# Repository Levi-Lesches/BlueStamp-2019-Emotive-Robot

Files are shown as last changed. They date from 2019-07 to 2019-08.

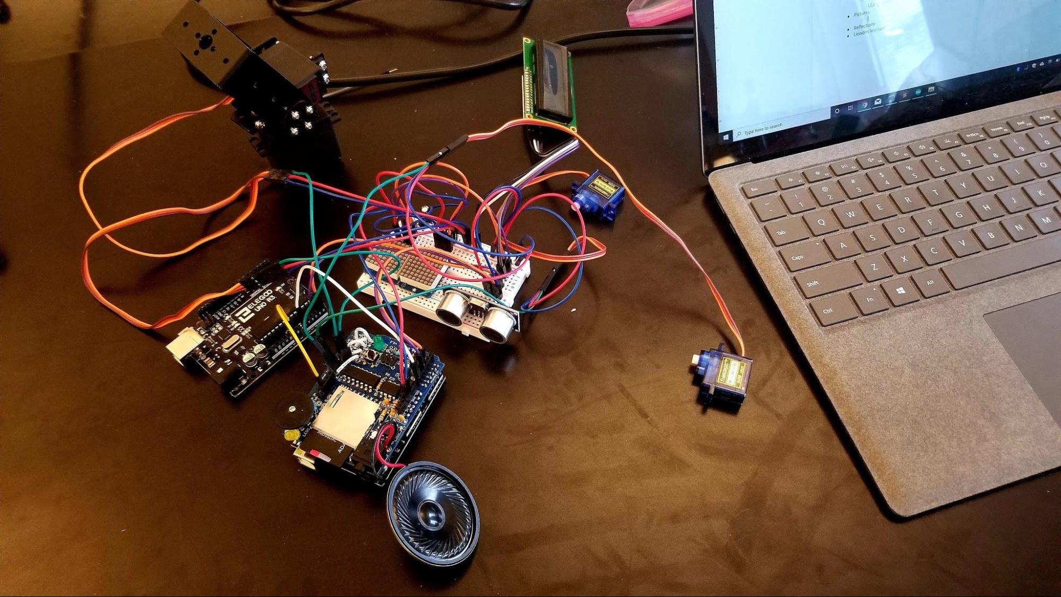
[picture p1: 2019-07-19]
documentation/Second Milestone/images/image2.jpg

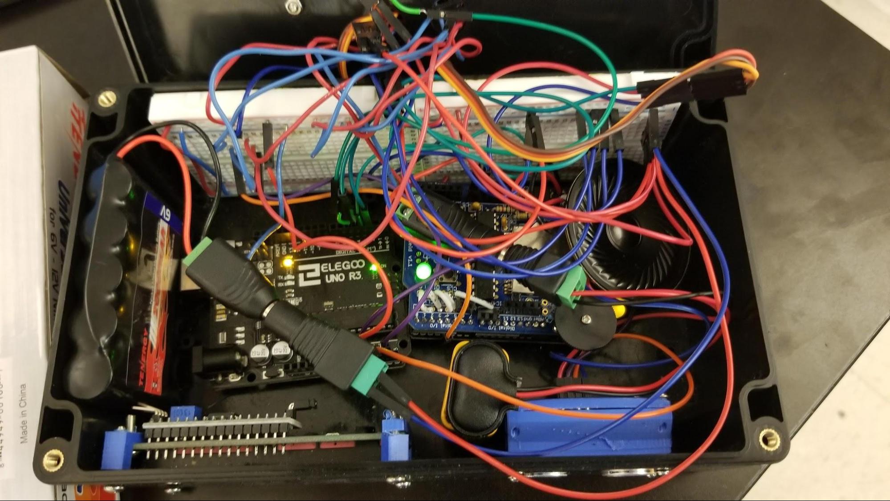
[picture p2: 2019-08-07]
documentation/Final milestone/images/image1.jpg

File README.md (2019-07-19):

# Emotive-Robot

A robot that interacts with you and is cute like WALL-E. I made this project in [BlueStamp Engineering](https://bluestampengineering.com), summer of 2019.  

Base project: 
- Has a robot body (from the neck up)
  - Has a head that can pan and tilt 
  - Has two LED matrices that act as eyes
  - Has eyebrows that can articulate emotion
- Can react to touch via an ultrasonic sensor
- Can play audio through a [Wave Shield](https://learn.adafruit.com/adafruit-wave-shield-audio-shield-for-arduino)
- Can display messages through an LCD screen
- Can be used one of two ways: 
  1. Autonmously. The robot will interact with you normally.
  2. Interactively. The robot can be controlled through a Bluetooth-connected app for Android.
  
Stretch goals: 
1. Add in a Raspberry Pi for more complex control with Python
2. Add a camera for Computer Vision functionality
3. Port the app to [Flutter](https://flutter.dev), so it can be used for Android and iOS
4. Have the robot mimic emotions using [emotional analysis](http://www.paulvangent.com/2016/04/01/emotion-recognition-with-python-opencv-and-a-face-dataset)
5. Have the robot take a picture of you and send it to your phone via Bluetooth
6. Use text-to-speech to let the robot speak messages instead of using the LCD
7. Use Artificial Intelligence to make custom messages (may need to be connected to the app)
8. Enable a security mode from the app: 
   1. Angry eyes
   2. Motion sensor set to alarm
   3. Have the speakers play an alarm sound
   4. Maybe send a notification from the app that the alarm was tripped.
9. Add idle animations to the LED matrices (eg, pong)

Documentation for this project can be found on my [Bluestamp project page](https://bluestampengineering.com/student-projects/levi-l).

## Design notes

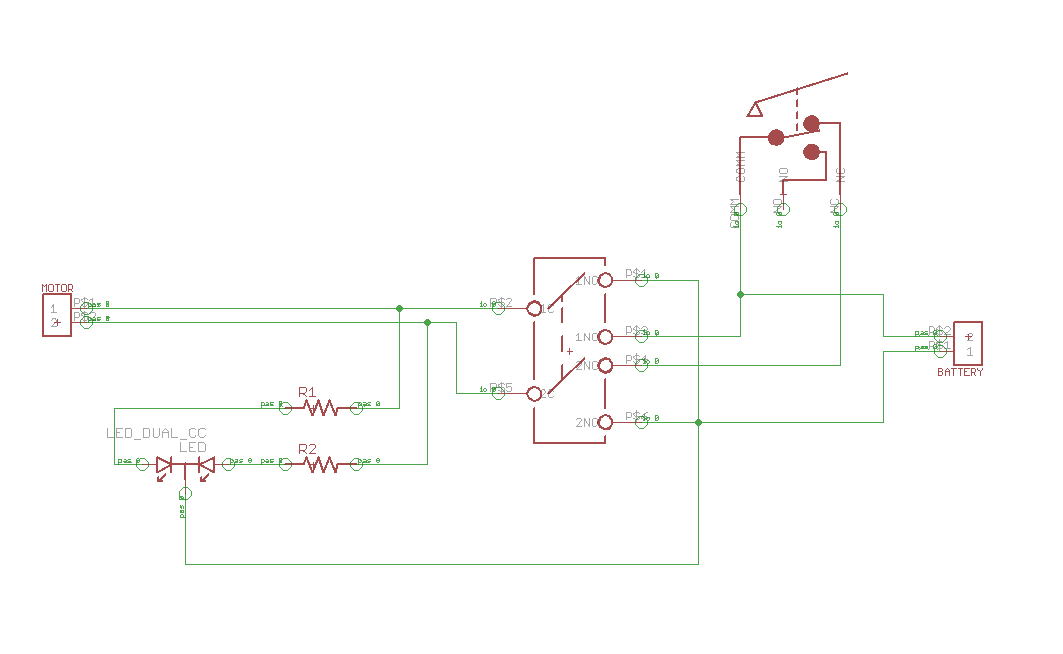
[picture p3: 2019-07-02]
starter/schematic.png

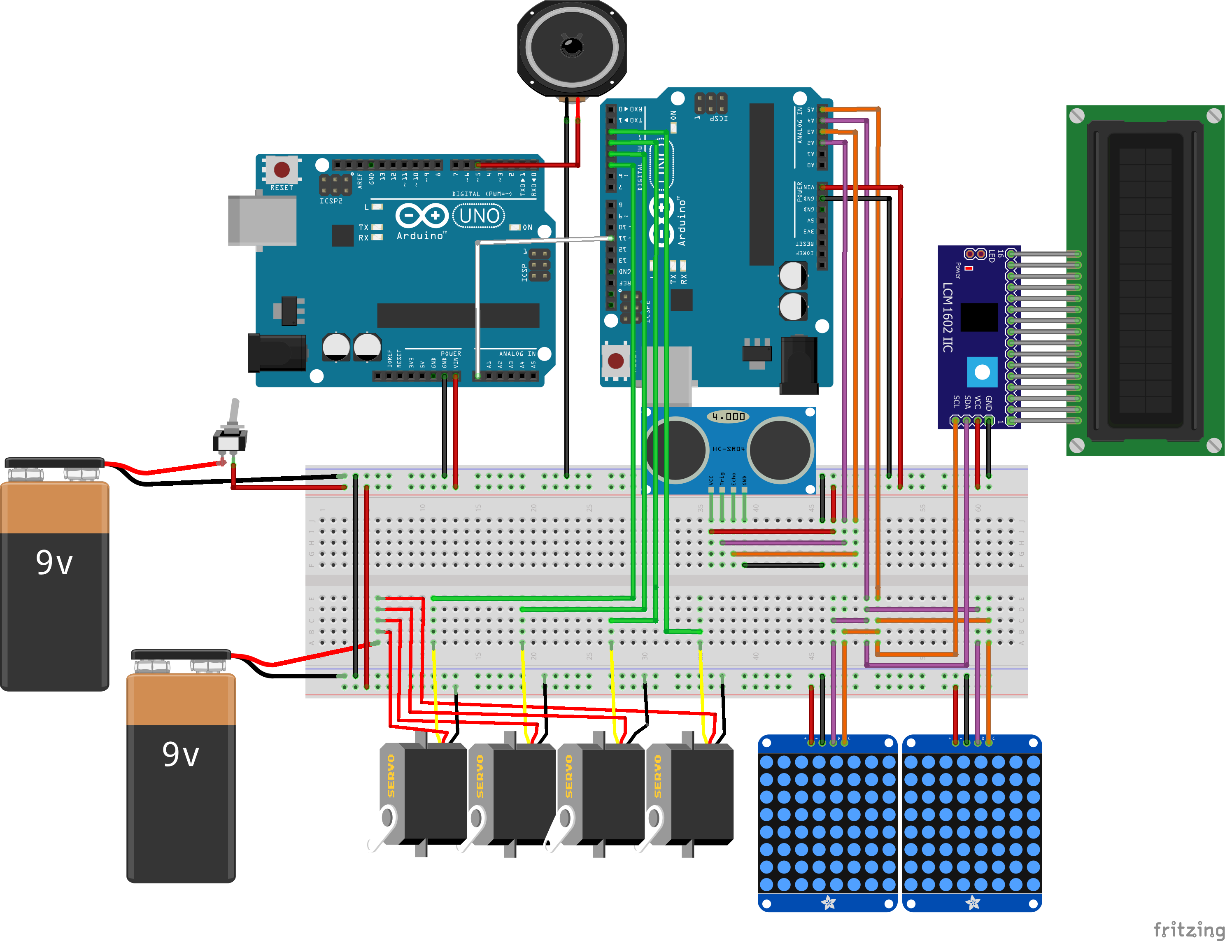
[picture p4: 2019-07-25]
fritzing/final.png

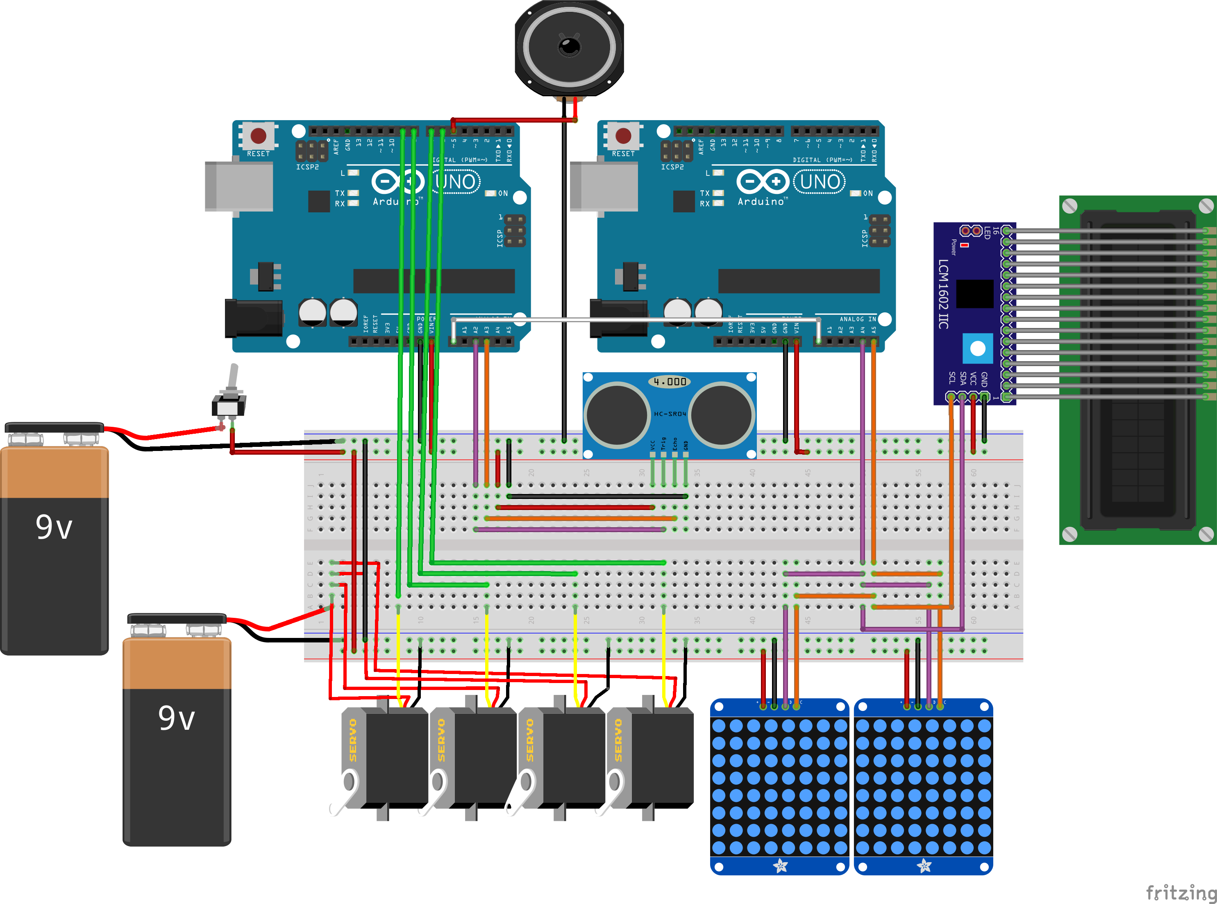
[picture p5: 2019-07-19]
documentation/Second Milestone/milestone2.png

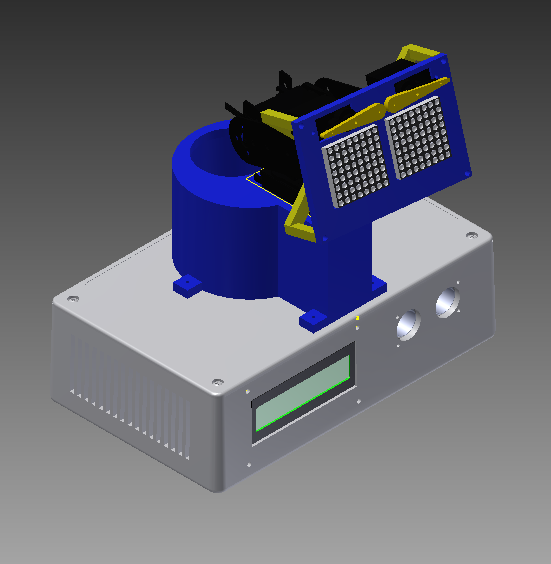
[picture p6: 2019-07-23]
3D/full.png

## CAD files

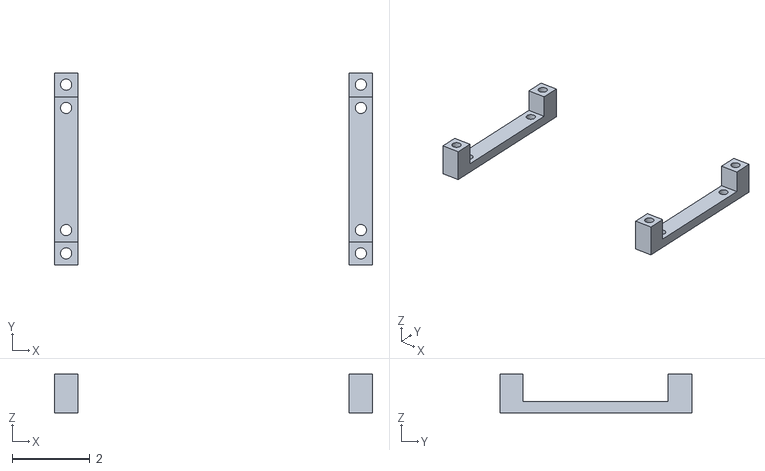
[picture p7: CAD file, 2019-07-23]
3D/Fusion files/Original/Enclosure/LCD/LCD_bracket.stl
8.20 x 4.95 x 1.00

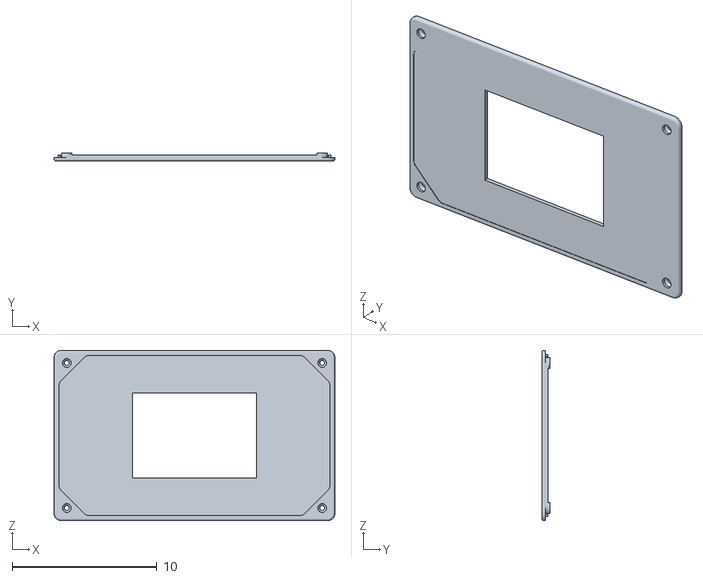
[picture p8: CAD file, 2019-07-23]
3D/Fusion files/Original/Enclosure/Lid.stl
19.4 x 0.584 x 11.8

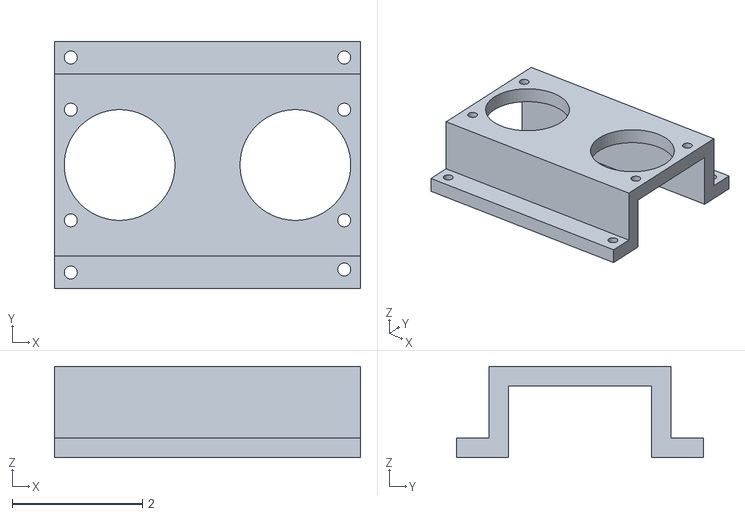
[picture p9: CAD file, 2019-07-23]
3D/Fusion files/Original/Enclosure/ProxSensor/ProxSensor_Bracket.stl
4.70 x 3.80 x 1.40

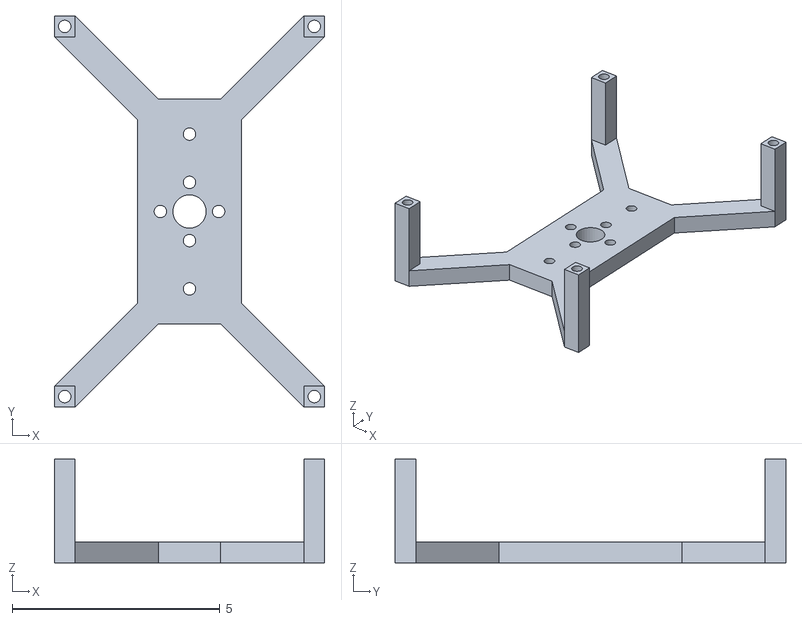
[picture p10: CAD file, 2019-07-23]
3D/Fusion files/Original/Enclosure/LCD/Face0.1.stl
6.50 x 9.40 x 2.50

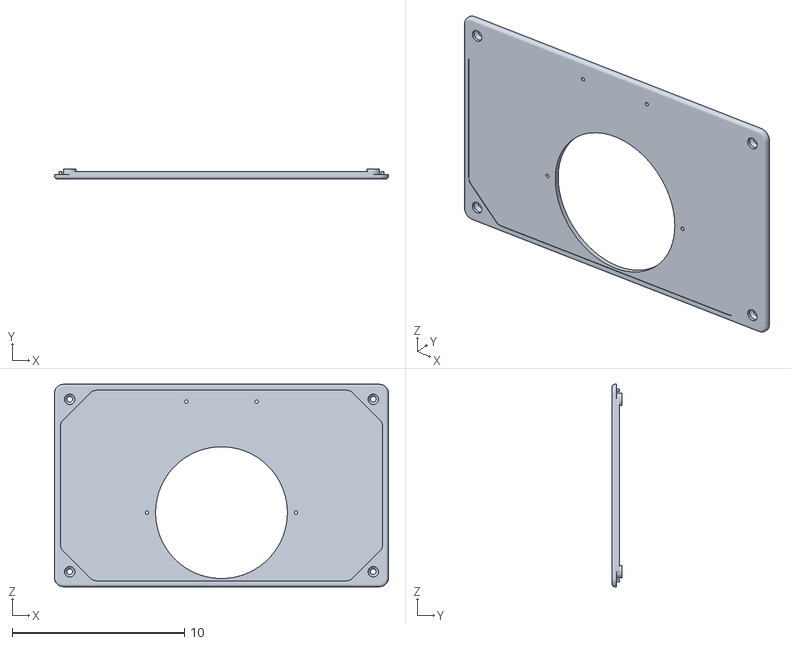
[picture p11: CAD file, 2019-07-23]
3D/Fusion files/Original/Enclosure/Lid0.1.stl
19.4 x 0.584 x 11.8

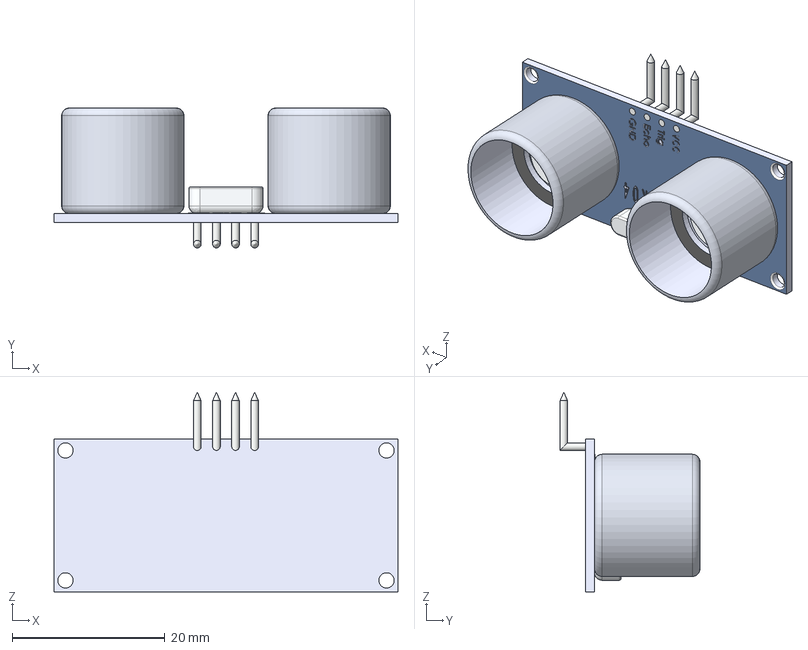
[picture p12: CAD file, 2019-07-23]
3D/Fusion files/Original/Enclosure/ProxSensor/hc-sr04.stp
45.0 x 18.3 x 26.1 mm

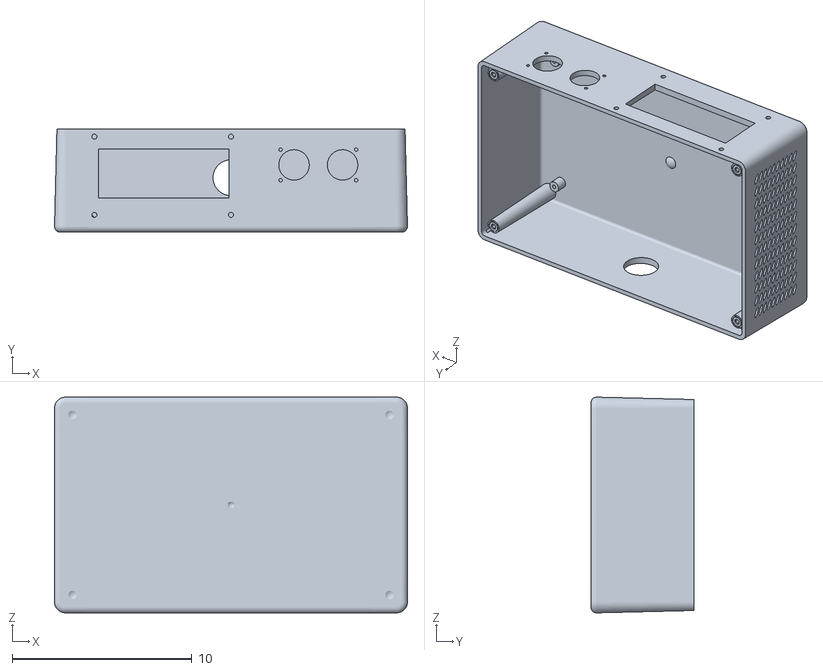
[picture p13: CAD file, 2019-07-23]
3D/Fusion files/Original/Enclosure/Bottom.stl
19.6 x 5.74 x 12.0

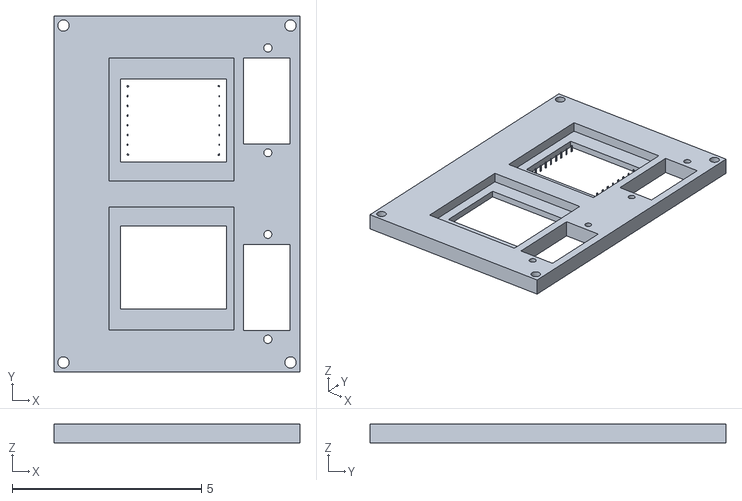
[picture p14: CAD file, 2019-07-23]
3D/Fusion files/Original/Enclosure/LCD/Face1.1.stl
6.50 x 9.40 x 0.5

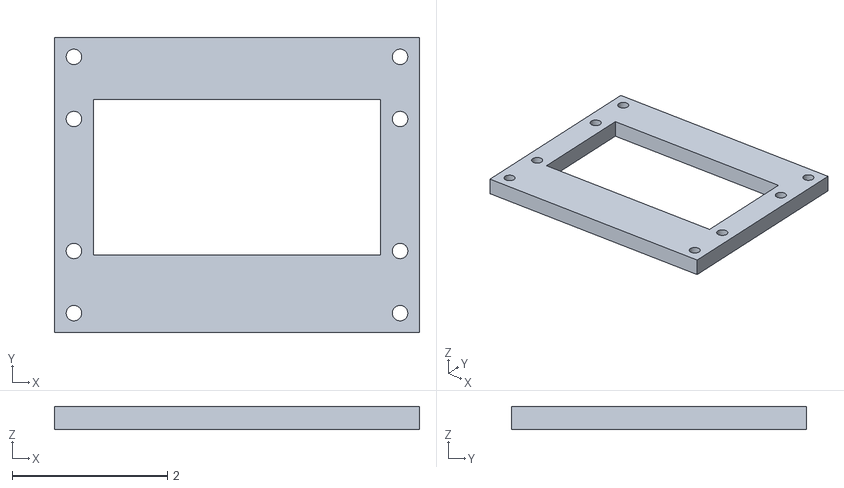
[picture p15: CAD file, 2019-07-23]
3D/Fusion files/Original/Enclosure/ProxSensor/ProxSensor_Bracket_Back.stl
4.70 x 3.80 x 0.3

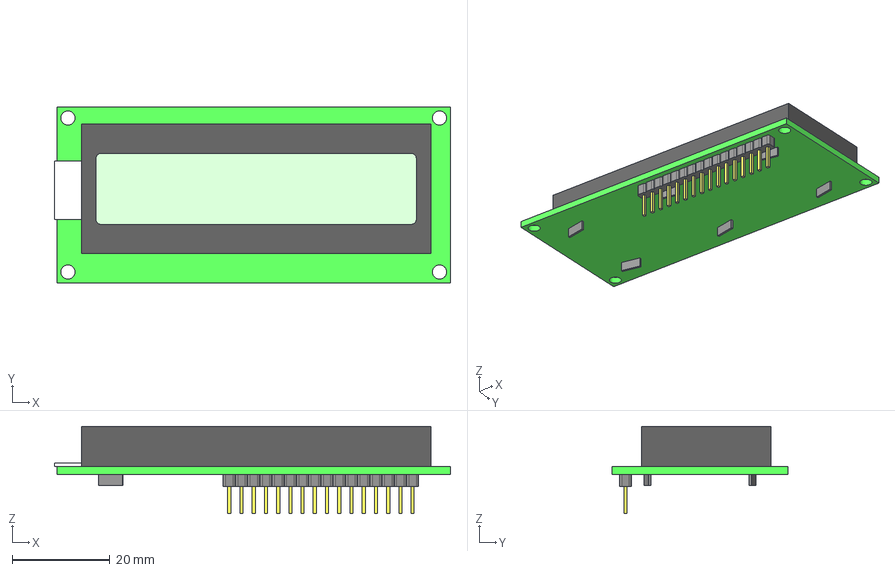
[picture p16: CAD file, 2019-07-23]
3D/Fusion files/Original/Enclosure/LCD/lcd1602 (1).stp
81.0 x 36.0 x 17.8 mm

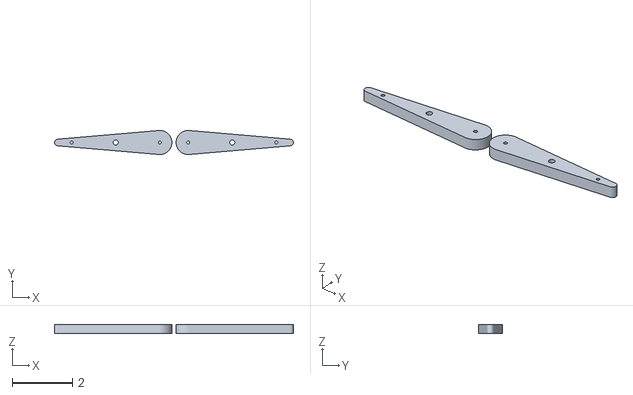
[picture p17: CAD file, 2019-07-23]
3D/Fusion files/Original/Enclosure/LCD/Eyebrows0.1.stl
7.92 x 0.8 x 0.3

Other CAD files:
3D/Fusion files/Original/Enclosure/Bottom0.1.stl
3D/Fusion files/Original/Enclosure/Bottom.ipt
3D/Fusion files/Original/Enclosure/Enclosure.iam
3D/Fusion files/Original/Enclosure/LCD/Eyebrows.ipt
3D/Fusion files/Original/Enclosure/LCD/Face.ipt
3D/Fusion files/Original/Enclosure/LCD/Face3.ipt
3D/Fusion files/Original/Enclosure/LCD/LCD.ipt
3D/Fusion files/Original/Enclosure/LCD/LCD_bracket.dxf
3D/Fusion files/Original/Enclosure/LCD/LCD_bracket.ipt
3D/Fusion files/Original/Enclosure/LCD/LCD_with_bracket.iam
3D/Fusion files/Original/Enclosure/LCD/Neck.ipt
3D/Fusion files/Original/Enclosure/LCD/OldVersions/Eyebrows.0001.ipt
3D/Fusion files/Original/Enclosure/LCD/OldVersions/Face.0002.ipt
3D/Fusion files/Original/Enclosure/LCD/OldVersions/Face3.0001.ipt
3D/Fusion files/Original/Enclosure/LCD/OldVersions/LCD_bracket.0002.ipt
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

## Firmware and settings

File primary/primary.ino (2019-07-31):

/*
	This is code for the primary Arduino. 

	It is in charge of emotion handling, which includes: 
		1. eyebrows
		2. eyes
		3. head/neck movements
		4. proximity sensor (to be surprised)

	So far, the head moves horizontally and vertically by the same random angle.
	If the ultrasonic sensor is triggered, the head moves more frequently, and
	the eyes get wider. After CALM_DOWN_DELAY, these behaviors stop. 

	NOTE: AUDIO IS DISABLED AS IT COULD NOT BE READY IN TIME FOR THE DEMO
	Audio is handled by the secondary Arduino, which is equipped with a Wave Shield
	Commands are sent using an analog signal which is used as an index to a list
	More details can be found in the code for the secondary Arduino

	Wiring for the primary Arduino:
		A3 --> proximity sensor echo (ECHO)
		A2 --> proximity sensor trigger (TRIGGER)
		2 --> pan servo (PAN)
		3 --> tilt servo (TILT)
		4 --> left eyebrow servo (LEFT_EYEBROW)
		5 --> right eyebrow servo (RIGHT_EYEBROW)

	Specs: 
		Storage space: 42% 
		Dynamic memory: 43%
*/

#include <Adafruit_LEDBackpack.h>
#include <LiquidCrystal_I2C.h>
#include <Servo.h>

// Servos
#define PAN 2
#define TILT 3
#define LEFT_EYEBROW 4
#define RIGHT_EYEBROW 5

// Proximity sensor
#define ECHO A3
#define TRIGGER A2
#define SENSOR_THRESHOLD 7  // cm, I believe

// Blinking
#define BLINK_DELAY 50
#define BLINK_INTERVAL 3000

// Moving the head
#define HEAD_MIN_ANGLE 60
#define HEAD_MAX_ANGLE 160

// Misc.
#define CALM_DOWN_DELAY 2500
#define NUM_EMOTIONS 2
#define NUM_MOVEMENT_FREQUENCIES 2
#define SIGNAL 11  // MUST BE PWM

// constants
const uint8_t BLINK[8] = {
	B00000000,
  B00000000,
  B00000000,
  B00000000,
  B00000000,
  B01000010,
  B00111100,
  B00000000,
};

const uint8_t BITMAPS[NUM_EMOTIONS][8] = {
	{  // NEUTRAL
		B00000000,
	  B00111100,
	  B01000010,
	  B01011010,
	  B01011010,
	  B01000010,
	  B00111100,
	  B00000000
	}, {  // SCARED
	  B01111110,
	  B10000001,
	  B10000001,
	  B10011001,
	  B10011001,
	  B10000001,
	  B10000001,
	  B01111110
	},
};

enum Sound {
	BLINK_SOUND,
	NEUTRAL_SOUND,
	SCARED_SOUND,
	NEUTRAL_MOVING_SOUND,
	SCARED_MOVING_SOUND,
};

enum Emotion {
	NEUTRAL, 
	SCARED,
};

enum MovementFrequency {
	ALERT, 
	NATURAL, 
};

const int movementDelays[NUM_MOVEMENT_FREQUENCIES] = {2, 5};

const MovementFrequency MOVEMENT_FREQUENCIES[NUM_EMOTIONS] = {
	ALERT, NATURAL,
};

const bool EYEBROW_DIRECTIONS[NUM_EMOTIONS] = {
	// NULL -> neutral, true -> up, false -> down
	NULL, true
};

const String MESSAGES[NUM_EMOTIONS] = {
	"Hello there", "WHOA!"
};

const Sound SOUNDS[NUM_EMOTIONS] = {
	NEUTRAL_SOUND, SCARED_SOUND
};

const Sound MOVING_SOUNDS[NUM_EMOTIONS] ={
	NEUTRAL_MOVING_SOUND, SCARED_MOVING_SOUND
};

// Hardware variables
Adafruit_8x8matrix matrix;
LiquidCrystal_I2C lcd = LiquidCrystal_I2C (0x27, 16, 2);
Servo pan, tilt, leftEyebrow, rightEyebrow;

// Software variables 
unsigned long lastBlink, lastMove, lastScared;
int movementDelay; // seconds
Emotion emotion;
MovementFrequency movementFrequency = NATURAL;

void sendSignal (int value) {
	// 0 is neutral, anything else is valid
	// to avoid 0, add 1 to the value
	analogWrite (SIGNAL, value + 1);
	delay (500);
	analogWrite (SIGNAL, 0);
}

void moveHead() {
	int angle = random (HEAD_MIN_ANGLE, HEAD_MAX_ANGLE);
	Serial.print("Moving to ");
	Serial.println(angle);
	pan.write(angle);
	tilt.write(angle);
	sendSignal(MOVING_SOUNDS[emotion]);
}

void setEyebrows(bool direction = NULL);
void setEyebrows(bool direction) {
	if (direction == NULL) direction = EYEBROW_DIRECTIONS[emotion];

	int angle = direction == NULL ? 90
		: direction ? 0 : 160;

	Serial.print("Moving eyebrows ");
	Serial.println(angle);

	int rightEyebrowAngle = abs (180 - angle);
	leftEyebrow.write(angle);
	rightEyebrow.write(rightEyebrowAngle);
}

void drawBitmap(uint8_t bitmap[8] = NULL);  // default argument
void drawBitmap(uint8_t bitmap[8]) {
	/* This function draws a bitmap onto the LED Matrix */

	if (bitmap == NULL) bitmap = BITMAPS[emotion];

	// drapBitmap(int x, int y, int bitmap[8], int width, int height, bool status)
	matrix.clear();
	matrix.drawBitmap (0, 0, bitmap, 8, 8, LED_ON);
	matrix.writeDisplay();  // needed to update matrix
}

void blink() {
	Serial.println ("Blinking");
	drawBitmap(BLINK);
	delay(BLINK_DELAY);
	sendSignal(BLINK_SOUND);
	drawBitmap(BITMAPS[emotion]);
}

void printMessage(String text = NULL);
void printMessage(String text) {
	if (text == NULL) text = MESSAGES[emotion];

	lcd.clear();  // just in case
	lcd.print(text);
	long distance = pulseIn(ECHO, HIGH) * 0.034 / 2;
}

void setEmotion(Emotion newEmotion) {
	Serial.print("Changing emotion to ");
	Serial.println(newEmotion);
	emotion = newEmotion;
	movementFrequency = MOVEMENT_FREQUENCIES [emotion];
	drawBitmap();
	setEyebrows();
	printMessage();
	sendSignal(SOUNDS[emotion]);
}

void setMovementFrequency(MovementFrequency frequency) {
	Serial.print ("Changing movement frequency to ");
	Serial.println(frequency);
	movementFrequency = frequency;
	movementDelay = MOVEMENT_FREQUENCIES[frequency];
}

bool isApproaching() {
	/* This function returns whether the user is close to the sensor */

	// Flush the current 
	digitalWrite(TRIGGER, LOW);
	delayMicroseconds(2);

	// Trigger a 10 micro-second sound wave
	digitalWrite(TRIGGER, HIGH);
	delayMicroseconds(10);
	digitalWrite(TRIGGER, LOW);

	// Read the incoming sound wave
	long distance = pulseIn(ECHO, HIGH) * 0.034 / 2;
	// Returns the distance (I'm relatively sure it's cm)
	return distance < SENSOR_THRESHOLD;
}

void setup() {
	Serial.begin(9600);
	Serial.println ("Setup...");

	// Servo setup
	pan.attach(PAN);
	tilt.attach(TILT);
	leftEyebrow.attach(LEFT_EYEBROW);
	rightEyebrow.attach(RIGHT_EYEBROW);

	// I2C devices
	Serial.println("Initializing matrices");
	matrix.begin(0x70);
	Serial.println("Matrices initialized");
	lcd.init();
	lcd.backlight();
	lcd.clear();

	// Proximity sensor
	pinMode (TRIGGER, OUTPUT);
	pinMode (ECHO, INPUT);

	// secondary Arduino communication
	pinMode (SIGNAL, OUTPUT);

	// Delay-based actions
	lastBlink = lastMove = lastScared = millis();

	// Set initial state
	setEmotion(NEUTRAL);
	setMovementFrequency(NATURAL);
}

void loop() {
	Serial.println("Processing");
	int time = millis();
	Serial.print("Timestamp: ");
	Serial.println(time);
	if (time - lastBlink >= BLINK_INTERVAL) {
		Serial.println("Blink time");
		blink();
		lastBlink = time;
	}
	if (time - lastMove >= movementDelay * 1000) {
		Serial.println("Time to move the head");
		moveHead();
		lastMove = time;
	}
	if (isApproaching()) {
		Serial.println("Something's here");
		if (emotion != SCARED) setEmotion(SCARED);
	}
	else if (emotion == SCARED && lastScared - time >= CALM_DOWN_DELAY) {
		Serial.println("Everything's OK");
		setEmotion(NEUTRAL);
	}
}

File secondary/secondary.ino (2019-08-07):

/*
	Code for the secondary Arduino.
	This device *only* controls audio, nothing else
	Analog signals are sent from the primary Arduino
	The signal sent corresponds with the index of the file in "filenames"

	It is important to keep audio functionality separate since the WaveHC 
	library uses a lot of memory thus straining any other functionality.  
	Additionally, WaveHC interferes with the Arduino's internal timers.

	Specs: 
		Storage space: 29%
		Dynamic memory: 77% (told you)
*/

#include <WaveHC.h>

#define SIGNAL A0
#define NUM_FILES 5

// This must sync up with the primary Arduino's Sounds enum
const String filenames[NUM_FILES] = {
	"BLINK.WAV", "NEUTRAL.WAV", "SCARED.WAV", "NEUTRMOV.WAV", "SCAREMOV.WAV"
};

WaveHC wave;  // store audio data
FatReader file, root;  // declare the file
FatVolume volume;  // Needed for reading the SD card
SdReader sdCard;  // declare the SD card

int getSignal() {
	return analogRead(SIGNAL);
}

void play(String stringName, bool interrupt) {
	// Copy the filename to a char array
	int length = stringName.length() + 2;  // get the length of the filename
	char name[length];  // declare the array
	stringName.toCharArray(name, length);  // store the string in the array

	// Actually play the file
	Serial.print("Playing ");
	Serial.println(name);
	file.open (root, name);  // store data in the file
	if (!wave.create (file))  // Invalid .wav file
		Serial.println ("Not a valid wave file");
	wave.play();  // actually play the .wav file

	if (interrupt) {  // need to stop all other code
		while (wave.isplaying) {  // print dots to the Serial monitor
			Serial.print(".");
			delay (100);
		}
	}
}

void setup() {
	Serial.begin (9600);

	Serial.println("Initializing SD card...");
	delay (1000);
	if (!sdCard.init()) Serial.println ("Card could not be read");
	sdCard.partialBlockRead(true);  // Cool little trick for faster reading
	
	// This just initializes file reading and writing
	if (!volume.init(sdCard)) Serial.println ("Volume could not be opened");
	if (!root.openRoot(volume)) Serial.println ("Root could not be opened");
	Serial.println ("Card initialized");
}

void loop(){
	int signal = getSignal();
	if (signal != 0)  // kill code
		// Use signal - 1 since we added 1 to avoid 0 (kill code)
		play(filenames [signal - 1], true);
	delay (500);
}

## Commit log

2019-07-02 Fixed error with sound
    [listFiles.ino, playSound.ino]
2019-07-05 First milestone complete
    Testing servos
2019-07-08 Got servos working with the wave shield
2019-07-09 Added code for the LCD and an I2C address scanner
2019-07-10 Added a sensor
2019-07-11 Going on a bit of a tangent to configure Servo timers
2019-07-12 Have secondary Arduino working
2019-07-12 Deleted the Servo.h library
2019-07-18 Added fritzing files
    [milestone2.fzz, temp.fzz]
2019-07-19 Fixed Fritzing file to reflect shared battery source
    Changed the echo and trig connections to the master Arduino
    [milestone2.fzz]
2019-07-19 Added 3D files
    [Bottom.0008.ipt, Bottom.ipt, Bottom.stl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]
2019-07-23 Printer ready
    [Back.ipt, Bottom.0008.ipt, Bottom.ipt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]
2019-07-23 3D printing ready
    [Back.ipt, Front.ipt, Ultrasonic.iam]
2019-07-24 Started logic for switching emotions
2019-07-25 Added slave code and updated Fritzing diagram
    [final.fzz, milestone2.fzz, temp.fzz]
2019-07-31 Commented `i2c.ino`
2019-07-31 Deleted `secondary.ino`
    It was replaced with `slave.ino`
    [secondary.ino]
2019-07-31 Commented `sensor.ino`
2019-07-31 Deleted `servos.ino`
    Since the servos were moved to the primary Arduino, ServoTimer2 is no longer needed.
